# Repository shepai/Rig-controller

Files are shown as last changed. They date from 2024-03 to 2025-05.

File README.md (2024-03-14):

# Rig-controller
Control a rig for manual testing of sensors

The controller is made up of four degrees of freedom. An x, y, z and tilt axis. We can use this platform to gather a series of directions, pressures, textures and angles to gather a robust dataset. This repository will provide the control for this rig so others can replicate the rig and generate their own data sets.

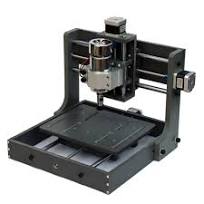
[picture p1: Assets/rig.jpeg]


The x axis is the plate moving back and fourth. The y axis moves the main body left and right. The z axis moves the sensor up and down, and the a axis tilts the plate.

We make use of a force matrix sensor such as the ones developed in the <a href="https://github.com/shepai/TactileSensor">tactile sensor repository</a> that is placed on top of the plate. This allows us to measure the force applied on the base to give extra labelling data that can be automatically gathered. 

## Set up
The Rig is controlled by a Raspberry Pi Pico. It uses I2C to connect to two Adafruit stepper motor controllers. One of the addresss (the board that controls axis z) must be soldered over to avoid desturbing the default pin address of the first board.

The rig works via serial connection to the PC device. The PC side code is in <a href="https://github.com/shepai/Rig-controller/tree/main/Code/boardSide">boardSide</a> whereas any code that runs on the device is under .

### Dependancies 
#### PC dependancies
- Serial
#### Circuit Python dependencies
- adafruit_motor
- <a href="https://github.com/shepai/TactileSensor">Tactile_CP</a>
- adafruit_register

The dependancies will need to be installed on the respective devices. 
The device should be using the example board code <a href="https://github.com/shepai/Rig-controller/blob/main/Code/Examples/Board%20Examples/listener.py">"listener.py"</a>, which will listen for the commands that our controller on the PC puts out. Adapt the code to use the parameter ```plate_mode=1``` or ```plate_mode=2``` if you are using one of the pressure pad boards. Otherwise nothing will be returned.

### Control
The rig, once wired makes use of a serial connection. We set up the PC library by importing it. The parameter should be the COM your board is on. "COM6" is an example.

```python
import Controller
c=Controller('COM6')
```

From here we can control read and write to the device. The listener will keep reading until the device sends "<" back. Bare in mind it will loop forever if your board never sends that symbol.

```python
import controller
c=Controller('COM6')
c.sendCommand('test command') #will be ignored
data=c.listen_for_data() #should return incorrect command
print("data recieved:",data)
```

To move the rig use the following commands:
```python
import controller
c=Controller('COM6')
x_value=10
y_value=12
z_value=-5
a_value=0
c.move(x_value,y_value,z_value,a_value) #move all of the motors by the set amounts
```

We can read pressure on the base with the command:

```python
import controller
c=Controller('COM6')
print("base pressures",c.getPressure())
```

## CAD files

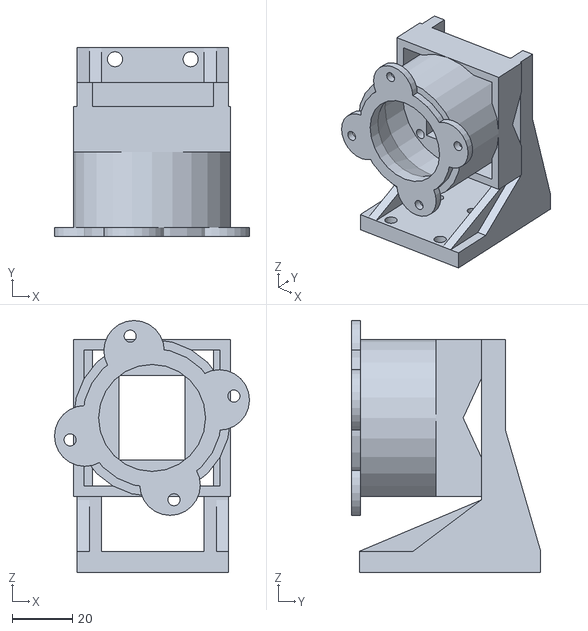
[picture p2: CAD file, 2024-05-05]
3D print files/TacTIp Rig.stl
64.5 x 62.7 x 83.3

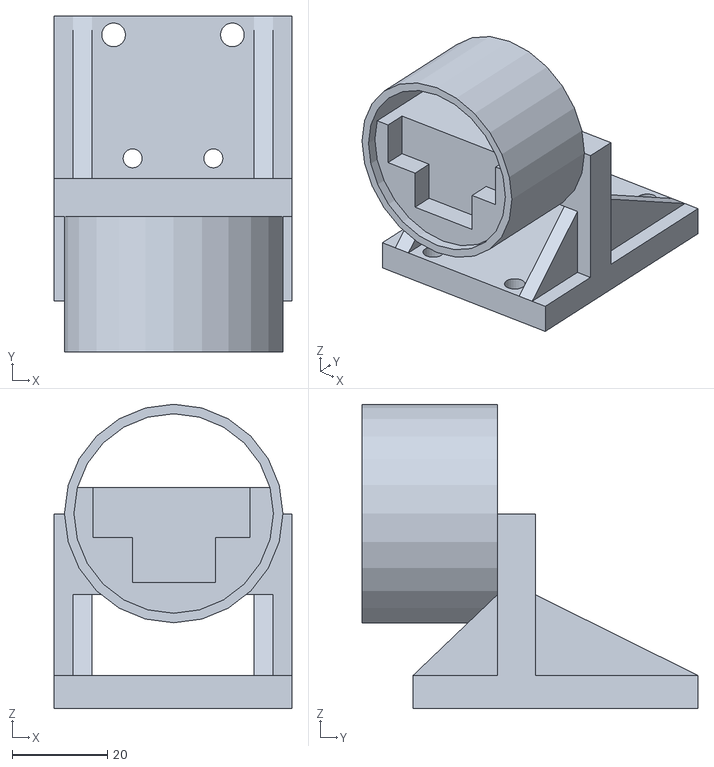
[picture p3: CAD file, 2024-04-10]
3D print files/Rig_presstip.stl
50.0 x 70.7 x 64.1

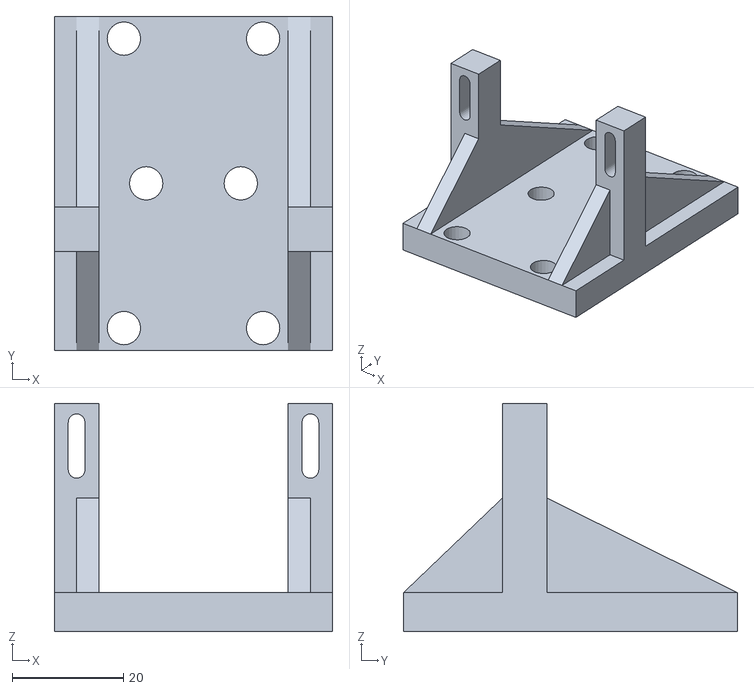
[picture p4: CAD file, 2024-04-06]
3D print files/RIG holder.stl
50.0 x 60.0 x 41.0

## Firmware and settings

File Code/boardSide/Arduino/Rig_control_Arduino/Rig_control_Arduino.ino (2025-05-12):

#include "Rig.h"
RigControl rig; //= RigControl(); // Use pin 13 for the LED

void setup() {
  Serial.begin(921600);
  Serial.print("Loaded Rig...");
  Serial.println("Scanning I2C bus...");
  Wire.begin();  // Start I2C communication
  // Scan for all I2C devices
  for (byte i = 8; i < 120; i++) {
    Wire.beginTransmission(i);
    byte error = Wire.endTransmission();
    
    if (error == 0) {
      Serial.print("Found device at address 0x");
      Serial.println(i, HEX);
    }
  }

  pinMode(LED_BUILTIN, OUTPUT);
  //rig=RigControl(); 
  rig.init();

}

void loop() {
  
    String command = "";
    char incomingChar = "";
    while (incomingChar != '\n') {
        if (Serial.available() > 0) {   // Ensure there is data to read
            incomingChar = Serial.read();
            // Only add valid ASCII characters (printable range: 32-126)
            if (incomingChar >= 32 && incomingChar <= 126) {
                command += incomingChar;
            }
        }
    }
    command.trim();
    if (incomingChar == '\n') {
      Serial.println("Command recieved");
      ProcessCommand(command);
      flash();
    }
}

void flash() {
  digitalWrite(LED_BUILTIN, HIGH);  // turn the LED on (HIGH is the voltage level)
  delay(100);                      // wait for a second
  digitalWrite(LED_BUILTIN, LOW);   // turn the LED off by making the voltage LOW
  delay(100);  
}
void ProcessCommand(String command) {
  Serial.println(command);
  if (command.startsWith("CALIB")) {
      Serial.println("Calibration");
      rig.calibrate();
      Serial.println("done");
  } else if (command == "ZERO") {
      Serial.println("Zeroing device");
      rig.zero();
      delay(10);
      Serial.println("done");
  } else if (command.startsWith("MOVE,")) {
      Serial.println("Moving rig...");
      int x, y, z, st;
      sscanf(command.c_str(), "MOVE,%d,%d,%d,%d", &x, &y, &z, &st);
      rig.setStep(st);
      rig.move(x, y, z);
      Serial.println("done");
  } else if (command=="RESET") {
      Serial.println("Resetting...");
      rig.reset();
      Serial.println("done");  
  }else if (command=="SHOW") {
      int* states = rig.readButtons();
      Serial.print(states[0]);Serial.print(states[1]);Serial.println(states[2]);
      Serial.println("done");
  }else if (command=="CENTRE") {
      Serial.print(positions[0]);Serial.print(positions[1]);Serial.println(positions[2]);
      rig.centre();
      Serial.println("done");
  }else {
      Serial.println("Unknown command");
      Serial.println("done");
  }
}

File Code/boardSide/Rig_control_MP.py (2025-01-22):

from adafruit_motorkit import MotorKit
from adafruit_motor import stepper
import busio
import board
from machine import Pin
import machine
import time
from Tactile_MP import Foot #found on my github
import hcsr04

class Rig:
    """
    Pinout

    I2C GP14 and GP15
    The buttons must be connceted to
    GP0,GP1 GP2 and GP3 each corrosponding to axis x,y,z,a
    Stepper motors must be x to board 1 y to board 1 z to board 2 a to board 2
    The foot or pressure sensor should be connected either through:
        I2C on 14 and 15
        or
        GP12, GP11, GP10, GP9 and the access pin to ground
    """
    def __init__(self,plate_mode=0):    
        #set up all i2c devices and motors
        self.i2c = busio.I2C(scl=board.GP25, sda=board.GP24)
        self.kit1 = MotorKit(address=0x70,i2c=self.i2c)
        self.kit2 = MotorKit(address=0x60,i2c=self.i2c)
        self.position=[-1,-1,-1,-1]
        self.motors=[self.kit1.stepper1,self.kit1.stepper2,self.kit2.stepper1,self.kit2.stepper2]
        #set up buttons
        # Define the pins for the buttons
        button_pins = [Pin(2,machine.Pin.IN,Pin.PULL_DOWN), Pin(8,machine.Pin.IN,Pin.PULL_DOWN), Pin(1,machine.Pin.IN,Pin.PULL_DOWN), Pin(0,machine.Pin.IN,Pin.PULL_DOWN)] #arduino 2,3,4,5
        
        # Initialize an array to hold the button objects
        self.buttons=button_pins
        #Initialise the plate
        self.plate=plate_mode
        if self.plate==1: #option one is normal plate
            self.sensor_plate=Foot([12,11,10,9],26,alpha=0.4)
        elif self.plate==2: #plate is i2c
           self.sensor_plate=Plate(Pin(26,machine.Pin.OUT),i2c=None,address=0x21,sda=None,scl=None,alpha=0.4)
        self.memory={"x":-1000,"y":-5200,"z":0,"a":0,"cx":0,"cy":0,"cz":0,"ca":0,"dist":9}
        self.inPosition=False
        #self.zero()
        trigger_pin = Pin(4, Pin.OUT)  # Change this to the pin connected to the trigger
        echo_pin = Pin(3, Pin.IN)      # Change this to the pin connected to the echo

        # Initialize the ultrasonic sensor
        self.sensor = hcsr04.HCSR04(trigger_pin, echo_pin)
    def reset(self,exclude=[1]):
        #move the rig till in the reset position
        buttons=self.readButtons()
        while 0 in [buttons[i] if i not in exclude else 1 for i in range(len(buttons))]: #loop till all pressed
            states=[(1-buttons[i])*100 for i in range(len(buttons))]
            self.moveMotors(states[3],states[2],states[0],states[1]) #only move ones not pressed
            buttons=self.readButtons()
    def getSensor(self):
        d=self.sensor.distance_cm()
        print(d)
        return d
    def moveMotors(self,x,y,z,a,style=stepper.DOUBLE):
        #move each motor by each value
        motors=[z*-1,a*1,y*1,x*1] #multiply by direction bias
        actualDir=[1 if x >= 0 else -1 for x in [z,a,y,x]]
        directions=[stepper.BACKWARD if motors[i]<0 else stepper.FORWARD for i in range(len(motors))]
        motors=[abs(motors[i]) for i in range(len(motors))]
        keys=["cz","ca","cy","cx"]
        top=max(motors)
        buttons=[0,0,0,0]
        for i in range(top): #schedule together
            for j in range(len(motors)):
                if i%2==0:#read every 2
                    buttons=self.readButtons()
                if motors[j]>0 and (buttons[j]==0 or actualDir[j]==-1):
                    self.motors[j].onestep(direction=directions[j], style=style)
                    motors[j]-=1
                    if self.inPosition: #if moved to position track movements
                        self.memory[keys[j]]-=actualDir[j]*1 #reverse direction to get back    
        print("moved")
    def readBase(self):
        #read the force on rig
        if self.plate>0:
            return self.sensor_plate.read()
        return -1
    def readButtons(self):
        states = []
        for button in self.buttons:
            states.append(button.value())
        return states
    def lowerSensor(self,average=5000):
        av=0
        turns=0
        alpha=0.5
        read=self.readBase()
        last_av=(sum(read)/len(read))
        while av<average:
            self.moveMotors(0,0,-50,0)
            read=self.readBase()
            av=(sum(read)/len(read))*alpha + (1-alpha)*last_av
            last_av=av
            print(av)
            turns-=50
        self.memory['z']=turns
    def setPerfect(self):
        self.memory['dist']=self.getSensor()
    def centre(self):
        reading=self.getSensor()
        dist=reading-self.memory["dist"]
        while abs(dist)>1.5:
            if dist>0: #move one way
                self.moveMotors(0,-10,0,0)
            else: #move other
                self.moveMotors(0,10,0,0)
            reading=self.getSensor()
            dist=reading-self.memory["dist"]
        
    def central(self):
        self.moveMotors(self.memory['x'],self.memory['y'],self.memory['z'],0)
        #extra movement
        self.centre()
        self.inPosition=True
    def close(self):
        pass
    def zero(self):
        nums=0
        for i in range(250):
            plate=self.readBase()
            nums+=(sum(plate)/len(plate))
        nums/=250
        self.zero_fact=nums

class client:
    def listen_for_command(self,command=""): #listen for command from the data
        return command
    def send(self,message):
        print(f">{message}<")

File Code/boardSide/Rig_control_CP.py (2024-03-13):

from adafruit_motorkit import MotorKit
import board
import busio
import time
import supervisor
from adafruit_motor import stepper
import digitalio
import ulab.numpy as np
from Tactile_CP import * #found on my github

class Rig:
    """
    Pinout

    I2C GP14 and GP15
    The buttons must be connceted to
    GP4,GP5 GP6 and GP7 each corrosponding to axis x,y,z,a
    Stepper motors must be x to board 1 y to board 1 z to board 2 a to board 2
    The foot or pressure sensor should be connected either through:
        I2C on 14 and 15
        or
        GP8, GP9, GP2, GP3 and the access pin to either ground or GP20
    """
    def __init__(self,plate_mode=0):    
        #set up all i2c devices and motors
        self.i2c = busio.I2C(board.GP14, board.GP15)
        self.kit1 = MotorKit(i2c=self.i2c)
        self.kit2 = MotorKit(address=0x71,i2c=self.i2c)
        self.position=[-1,-1,-1,-1]
        self.motors=[self.kit1.stepper1,self.kit1.stepper2,self.kit2.stepper1,self.kit2.stepper2]
        #set up buttons
        # Define the pins for the buttons
        button_pins = [board.GP4, board.GP5, board.GP6, board.GP7] #arduino 2,3,4,5

        # Initialize an array to hold the button objects
        buttons = []
        for pin in button_pins:
            button = digitalio.DigitalInOut(pin)
            button.direction = digitalio.Direction.INPUT
            button.pull = digitalio.Pull.UP
            buttons.append(button)
        self.buttons=buttons
        #Initialise the plate
        self.plate=plate_mode
        if self.plate==1: #option one is normal plate
            pins=[board.GP8, board.GP9, board.GP2, board.GP3]
            self.sensor_plate=Foot(pins,board.GP26,board.GP20,alpha=0.2)
        elif self.plate==2: #plate is i2c
           self.sensor_plate=Plate(board.GP26,i2c=None,address=0x21,sda=None,scl=None,alpha=0.1)

    def resetRig(self):
        #move the rig till in the reset position
        while sum(self.readButtons())>0: #loop till all pressed
            states=np.ones((4,))*np.array(self.readButtons())
            self.moveMotors(states[0],states[1],states[2],states[3]) #only move ones not pressed
    def moveMotors(self,x,y,z,a,style=stepper.SINGLE):
        #move each motor by each value
        motors=[x,y,z,a]
        directions=[stepper.BACKWARD if motors[i]<0 else stepper.FORWARD for i in range(len(motors))]
        for i in range(max(motors)): #schedule together
            for j in range(len(motors)):
                if motors[j]>0:
                    self.motors[j].onestep(direction=directions[j], style=style)
                    motors[j]-=1
    def readBase(self):
        #read the force on rig
        if self.plate>0:
            return self.sensor_plate.read()
        return -1
    def readButtons(self):
        states = []
        for button in self.buttons:
            states.append(button.value)
        return states

class client:
    def listen_for_command(self): #listen for command from the data
        value=""
        while value=="":
            if supervisor.runtime.serial_bytes_available:
                value = input().strip()
        return value
    def send(self,message):
        print(f">{message}<")
    

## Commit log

2024-03-06 pcb design
    [pressurePlate.kicad_pcb]
2024-03-14 send commands to device
2024-03-29 Create RIG holder.stl
    [RIG holder.stl]
2024-04-05 Update RIG holder.stl
    [RIG holder.stl]
2024-04-17 visualise sensor
2024-05-01 Update TacTIp Rig.stl
    [TacTIp Rig.stl]
2025-02-18 arduino attempt
2025-02-18 working buttons
2025-02-19 rig functioning arduino
2025-02-21 all motors working
2025-04-03 working arduino?
